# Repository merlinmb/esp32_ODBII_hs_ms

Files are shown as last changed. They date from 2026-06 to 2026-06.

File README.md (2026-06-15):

# Ford Focus 2008 — Dual CAN OBD-II Logger

ESP32-S3 firmware for the **Lilygo T2-CAN** board. Reads both the High-Speed (HS) and Medium-Speed (MS) CAN buses from a Ford Focus 2008 OBD-II connector, hosts a live web dashboard, and publishes data to a Mosquitto MQTT broker.

---

## What It Does

| Feature | Detail |
|---|---|
| HS-CAN (500 kbps) | RPM, speed, coolant temp, IAT, MAF, throttle %, battery voltage, oil temp, DTCs |
| MS-CAN (125 kbps) | Fuel level (Ford broadcast, CAN ID 0x420) |
| Web dashboard | Dark-theme card grid, auto-refreshes every 5 s, served on port 80 |
| MQTT | Publishes full JSON payload every 30 s (configurable) |
| Config | All credentials and pin assignments in `credentials.h` |

---

## Hardware

### Lilygo T2-CAN V1.0

The T2-CAN V1.0 uses a **hybrid CAN architecture** — not two native TWAI controllers as the board name might imply:

| Bus | Controller | Interface | GPIO |
|-----|---|---|---|
| CAN A — HS-CAN (500 kbps) | MCP2515 (external SPI) | SPI | CS=10, SCLK=12, MOSI=11, MISO=13 |
| CAN B — MS-CAN (125 kbps) | ESP32-S3 native TWAI | Direct | TX=7, RX=6 |

The MCP2515 also has a hardware reset (GPIO 9) and interrupt (GPIO 8) line. Pin definitions are in `include/credentials.h` and match the [official LilyGo T2-CAN pin_config.h](https://github.com/Xinyuan-LilyGO/T-2Can/blob/main/libraries/private_library/pin_config.h).

### I2C OLED Display (SH1106 128×64)

Connect via the QWIIC/I2C connector on the board.

**Default pin assignments (adjust in `credentials.h` if different):**

| Signal | GPIO |
|---|---|
| I2C SDA | 17 |
| I2C SCL | 18 |

---

## OBD-II Wiring

The connector used for this build is an [OBD-II 16-pin breakout cable (Amazon UK)](https://www.amazon.co.uk/dp/B0F2HTKXRH?ref=ppx_yo2ov_dt_b_fed_asin_title), which exposes individual colour-coded wires for each pin.

### Wire colour reference (cable pin-out)

| OBD-II Pin | Wire Colour | Standard Function |
|:---:|---|---|
| 1 | Black | Manufacturer-defined |
| 2 | Brown | Manufacturer-defined |
| 3 | Red | MS-CAN High (Ford) |
| 4 | Orange | Chassis Ground |
| 5 | Yellow | Signal Ground |
| 6 | Green | HS-CAN High |
| 7 | Blue | K-Line / ISO 9141 |
| 8 | Purple | Manufacturer-defined |
| 9 | Grey | Manufacturer-defined |
| 10 | White | Manufacturer-defined |
| 11 | Pink | MS-CAN Low (Ford) |
| 12 | Light Green | Manufacturer-defined |
| 13 | Black/White | Manufacturer-defined |
| 14 | Brown/White | HS-CAN Low |
| 15 | Red/White | Manufacturer-defined |
| 16 | Green/White | Battery +12 V |

### T2-CAN connector wiring

#### CAN Bus A — HS-CAN (500 kbps, OBD-II standard)

| T2-CAN Pin | Signal | OBD-II Pin | Wire Colour |
|---|---|:---:|---|
| CANHA | CAN High | 6 | Green |
| CANLA | CAN Low | 14 | Brown/White |
| SGNDA | Signal Ground | 5 | Yellow |
| DGNDA | Digital Ground | 4 | Orange |

#### CAN Bus B — MS-CAN (125 kbps, Ford Medium Speed)

| T2-CAN Pin | Signal | OBD-II Pin | Wire Colour |
|---|---|:---:|---|
| CANHB | CAN High | 3 | Red |
| CANLB | CAN Low | 11 | Pink |
| SGNDB | Signal Ground | 5 | Yellow (shared with Bus A) |
| DGNDB | Digital Ground | 4 | Orange (shared with Bus A) |

#### Power

| T2-CAN Pin | Signal | OBD-II Pin | Wire Colour |
|---|---|:---:|---|
| VIN | +12 V battery | 16 | Green/White |
| GND | Power Ground | 4 | Orange |

> **Note:** OBD-II pins 3 and 11 are Ford-proprietary MS-CAN. They are not present on non-Ford vehicles.

> **Termination:** The vehicle's CAN buses are already terminated at the ECU end. Do **not** add external 120 Ω resistors — the T2-CAN transceivers have on-board termination jumpers; leave them **open** (or cut the trace) when connecting to an in-vehicle bus.

---

## Ford Focus 2008 CAN Bus Notes

### HS-CAN (500 kbps)
Carries powertrain data. Accessed via standard OBD-II Mode 01 PIDs using functional address `0x7DF`. ECU responds on `0x7E8`.

### MS-CAN (125 kbps)
Carries body/comfort data (fuel gauge, HVAC, instrument cluster). Ford ECUs broadcast data continuously — no request frames needed. The firmware listens passively.

**Known MS-CAN broadcast IDs:**

| CAN ID | Content | Byte | Formula |
|---|---|---|---|
| 0x420 | Fuel level | 0 | `byte / 2.55` → % |

Additional IDs can be added in `src/can_ms.cpp` as you discover them with a CAN sniffer.

---

## Ford Focus MK2 (2007–2008, UK) — Model-Specific Notes

This section documents the specific CAN bus architecture of the **Ford Focus MK2 C170 platform** (2005–2008, UK market) and confirms compatibility with this firmware.

### Dual CAN Bus Architecture

The Focus MK2 is one of Ford's earliest models to use a dual-bus CAN architecture. This is why a standard ELM327 dongle cannot access body modules without a hardware HS/MS-CAN toggle switch (as sold by ELMConfig/FORScan adapters) — a standard OBD-II dongle only sees pins 6 and 14 (HS-CAN).

| Bus | OBD-II Pins | Speed | Purpose |
|-----|---|---|---|
| HS-CAN | Pin 6 (High), Pin 14 (Low) | 500 kbps | Powertrain, ABS, transmission |
| MS-CAN | Pin 3 (High), Pin 11 (Low) | 125 kbps | Body, comfort, instrument cluster |

> Pins 3 and 11 are **Ford-proprietary** — they carry no signal on non-Ford vehicles.

### Which Modules Live on Each Bus

**HS-CAN (500 kbps) — accessed by this firmware via MCP2515:**

| Module | Abbrev | What it provides |
|---|---|---|
| Powertrain Control Module | PCM | RPM, speed, temps, MAF, throttle, DTCs |
| Transmission Control Module | TCM | Gear, torque |
| Anti-lock Braking System | ABS/HEC | Wheel speeds |
| Electric Power Assisted Steering | EHPAS | Steering load |
| Body Control Module | BCM | Some body signals |

**MS-CAN (125 kbps) — listened to passively by this firmware via TWAI:**

| Module | Abbrev | What it provides |
|---|---|---|
| Generic Electronic Module | GEM | Lighting, wipers, central locking |
| Driver/Passenger Door Modules | DDM / PDM | Window, mirror control |
| Electronic Automatic Temp Control | EATC | Climate |
| Restraints Control Module | RCM | Airbag |
| Instrument Cluster | IC | Fuel gauge, odometer, warnings |
| Keyless Vehicle Module | KVM | Remote locking |
| Parking Aid Module | PAM | Sensors |

### OBD-II Diagnostic Protocol (HS-CAN)

The Focus MK2 UK uses **ISO 15765-4** (CAN 11-bit, 500 kbps) for OBD-II diagnostics. All standard Mode 01 PIDs are supported:

| PID | Parameter | Formula |
|-----|---|---|
| 0x0C | Engine RPM | `((A×256)+B) / 4` |
| 0x0D | Vehicle speed | `A` km/h |
| 0x05 | Coolant temperature | `A − 40` °C |
| 0x0F | Intake air temperature | `A − 40` °C |
| 0x10 | MAF air flow | `((A×256)+B) / 100` g/s |
| 0x11 | Throttle position | `A × 100 / 255` % |
| 0x42 | Battery voltage | `((A×256)+B) / 1000` V |
| 0x5C | Oil temperature | `A − 40` °C |
| 0x01 | DTC status / MIL | Bit 7 of A = MIL on/off; bits 0–6 = DTC count |

Request address: `0x7DF` (functional broadcast to all ECUs)
Response address: `0x7E8` (PCM — engine ECU)

### MS-CAN Fuel Level (Unverified — Needs In-Car Confirmation)

The instrument cluster on the MS-CAN bus broadcasts fuel level as a periodic frame. CAN ID `0x420`, byte 0, scaled as `byte / 2.55` → % is **widely cited in Ford reverse-engineering communities** for this platform, but has not been independently verified against a production UK MK2.

**To verify or find the correct ID on your car:**

1. Enable serial logging and watch MS-CAN output — the firmware logs all unrecognised frame IDs at debug level
2. With a nearly-full tank, note which IDs are present
3. Remove ~5 litres, re-check — the ID whose byte 0 value changed is the fuel level frame
4. Update `MS_ID_FUEL_LEVEL` in `src/can_ms.cpp` if the ID differs

### Termination

Do **not** add 120 Ω termination resistors. The vehicle bus is already terminated at both ends (ECU and instrument cluster). The T2-CAN board has optional termination jumpers — leave them **open** when connected to an in-vehicle bus, otherwise you'll create a 60 Ω net impedance and cause bus errors.

### Known Limitations on This Platform

- **Oil temperature (PID 0x5C):** May not be supported on all MK2 engine variants. The 1.6 Duratec petrol does not have an oil temp sensor — PID queries will time out silently.
- **Battery voltage (PID 0x42):** Returns ECU supply voltage, not alternator voltage directly. Values are typically 13.8–14.4 V at idle with engine running.
- **MAF (PID 0x10):** Not present on diesel variants (use MAP instead). Queries will time out on TDCi engines.
- **MS-CAN availability:** The MS-CAN bus is only active with ignition on (position II). It goes silent within seconds of key-off, which will trigger the MS-CAN silence timeout in the firmware.

---

## Software Setup

### Prerequisites

- [PlatformIO](https://platformio.org/) (VS Code extension or CLI)
- USB cable to COM3

### 1. Clone / open the project

Open the `esp32_ODBII_hs_ms` folder in VS Code with the PlatformIO extension installed.

### 2. Create credentials

```bash
cp credentials.h.example credentials.h
```

Edit `credentials.h` and fill in your values:

```cpp
#define WIFI_SSID              "MyNetwork"
#define WIFI_PASSWORD          "MyPassword"
#define MQTT_BROKER            "192.168.1.100"
#define MQTT_PORT              1883
#define MQTT_TOPIC             "car/focus/obd"
#define MQTT_PUBLISH_INTERVAL_MS  30000   // 30 s

// T2-CAN V1.0 — MCP2515 SPI pins for HS-CAN
#define MCP2515_CS_PIN         10
#define MCP2515_RST_PIN        9
#define MCP2515_INT_PIN        8
#define SPI_SCLK_PIN           12
#define SPI_MOSI_PIN           11
#define SPI_MISO_PIN           13

// T2-CAN V1.0 — native TWAI pins for MS-CAN
#define CAN_MS_TX_PIN          7
#define CAN_MS_RX_PIN          6
```

### 3. Build and flash

```bash
pio run --target upload
```

Or use the PlatformIO toolbar in VS Code (→ Upload).

### 4. Monitor serial output

```bash
pio device monitor
```

The device prints WiFi connection status, CAN bus state, and each MQTT publish to the serial console at 115200 baud.

---

## Web Dashboard

Once connected to WiFi, open a browser to the device's IP address (printed on serial):

```
http://192.168.x.x/
```

The dashboard auto-refreshes every 5 seconds. Values turn amber when stale (> 10 s since last CAN update) and red when the bus is disconnected.

The raw JSON data is also available at:

```
http://192.168.x.x/data
```

---

## MQTT Payload

Published as a flat JSON object to the configured topic:

```json
{
  "rpm": 820.0,
  "speed_kmh": 0.0,
  "coolant_temp_c": 87.5,
  "intake_air_temp_c": 22.0,
  "maf_g_per_s": 3.1,
  "throttle_pct": 0.0,
  "battery_voltage": 14.1,
  "oil_temp_c": 91.0,
  "dtc_present": false,
  "dtc_count": 0,
  "fuel_level_pct": 62.4,
  "hs_connected": true,
  "ms_connected": true
}
```

---

## Project Structure

```
credentials.h          — your local config (gitignored)
credentials.h.example  — template committed to repo
platformio.ini         — build config, COM3, board
src/
  main.cpp             — setup, loop, FreeRTOS task launch
  obd_data.h           — shared VehicleData struct + mutex
  can_hs.h / .cpp      — HS-CAN FreeRTOS task (OBD-II request/response)
  can_ms.h / .cpp      — MS-CAN FreeRTOS task (Ford broadcast listener)
  web_server.h / .cpp  — async HTTP server, HTML in PROGMEM
  mqtt_client.h / .cpp — MQTT publish wrapper
docs/
  superpowers/specs/   — design documentation
```

---

## Troubleshooting

| Symptom | Likely cause |
|---|---|
| CAN bus install fails | Wrong GPIO pins — check `credentials.h` against your board schematic |
| HS-CAN shows no data | Bus speed mismatch or missing termination — verify 500 kbps |
| MS-CAN fuel stays 0 | CAN ID 0x420 not present on your trim — sniff the bus to find the correct ID |
| WiFi not connecting | Check SSID/password in `credentials.h`; device must be on 2.4 GHz |
| MQTT not publishing | Check broker IP, port 1883 open, no auth required (or add auth to `mqtt_client.cpp`) |
| Web page not loading | Find IP in serial monitor; ensure device and browser on same subnet |

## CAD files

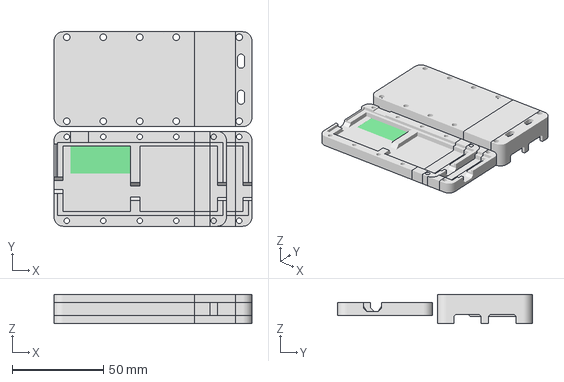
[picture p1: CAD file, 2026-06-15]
3dmodels/Lilygo_T_2Can_Enclosure_extended components.3mf
108.5 x 106.6 x 16.0 mm

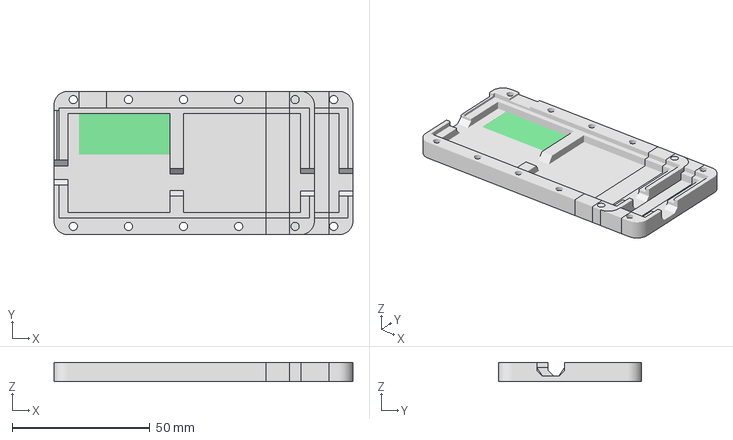
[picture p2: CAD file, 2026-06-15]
3dmodels/Lilygo_T_2Can_Enclosure_base_v2.3mf
108.5 x 52.0 x 7.00 mm

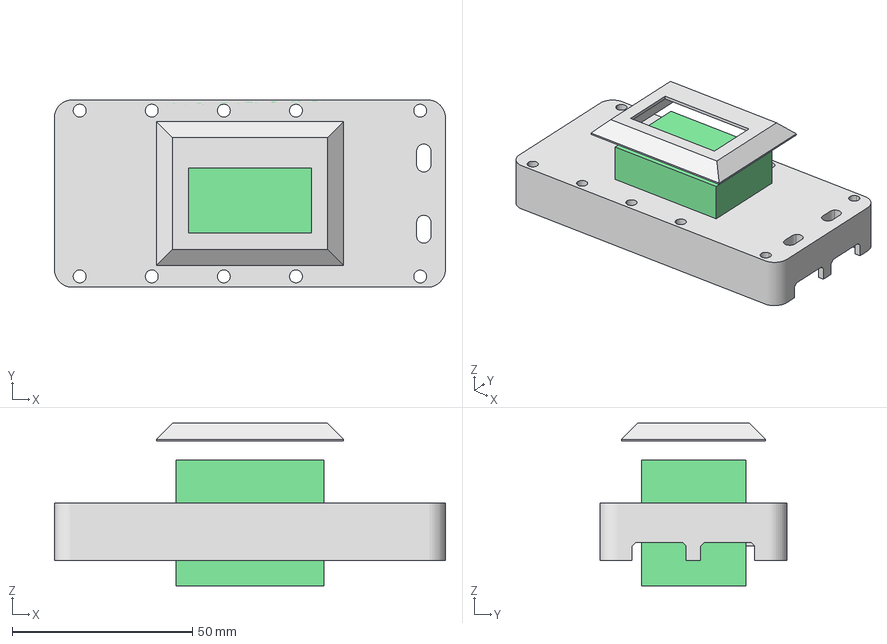
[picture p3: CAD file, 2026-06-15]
3dmodels/Lilygo_T_2Can_Enclosure_Top_v2.3mf
108.5 x 52.0 x 45.1 mm

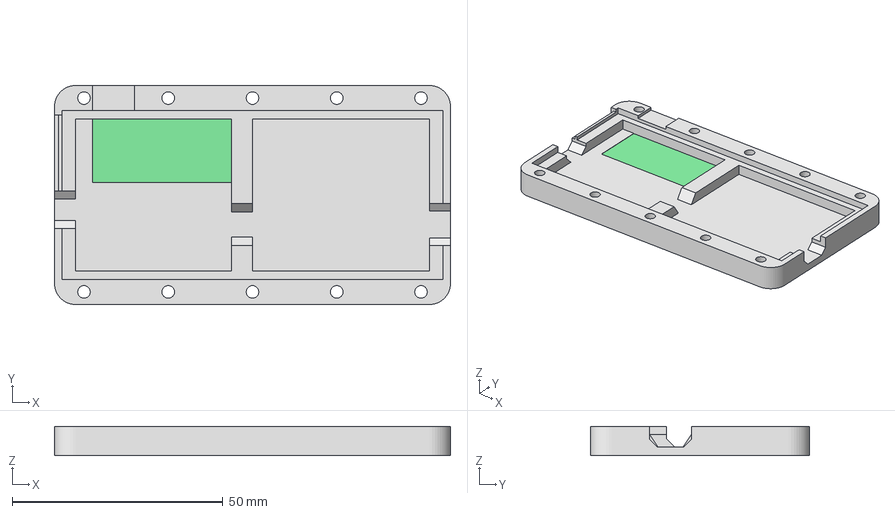
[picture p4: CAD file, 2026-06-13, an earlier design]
3dmodels/Lilygo_T_2Can_Enclosure_base.3mf
94.0 x 52.0 x 7.00 mm

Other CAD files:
3dmodels/Lilygo_T_2Can_Enclosure_Top_v2.stl
3dmodels/Lilygo_T_2Can_Enclosure_base.stl
3dmodels/Lilygo_T_2Can_Enclosure_base_v2.stl

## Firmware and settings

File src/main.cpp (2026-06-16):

#include <Arduino.h>
#include <SPI.h>
#include <WiFi.h>
#include "credentials.h"
#include "obd_data.h"
#include "can_hs.h"
#include "can_ms.h"
#include "web_server.h"
#include "mqtt_client.h"
#include "sleep_manager.h"
#include "display.h"
#include "esp_sleep.h"

// Globals defined here, declared extern in obd_data.h
VehicleData g_vehicle = {
    .rpm               = NAN,
    .speed_kmh         = NAN,
    .coolant_temp_c    = NAN,
    .intake_air_temp_c = NAN,
    .maf_g_per_s       = NAN,
    .throttle_pct      = NAN,
    .battery_voltage   = NAN,
    .oil_temp_c        = NAN,
    .fuel_level_pct    = NAN,
};
SemaphoreHandle_t g_data_mutex = nullptr;

static WiFiClient s_mqtt_wifi_client;

static void wifi_connect() {
    Serial.printf("[WiFi] connecting to %s ...\n", WIFI_SSID);
    WiFi.mode(WIFI_STA);
    WiFi.begin(WIFI_SSID, WIFI_PASSWORD);
    uint8_t attempts = 0;
    while (WiFi.status() != WL_CONNECTED && attempts < 30) {
        delay(500);
        Serial.print('.');
        attempts++;
    }
    Serial.println();
    if (WiFi.status() == WL_CONNECTED) {
        Serial.printf("[WiFi] connected, IP: %s\n", WiFi.localIP().toString().c_str());
    } else {
        Serial.println("[WiFi] failed to connect — continuing without network");
    }
}

void setup() {
    Serial.begin(115200);
    delay(500);

    esp_sleep_wakeup_cause_t wakeup = esp_sleep_get_wakeup_cause();
    if (wakeup == ESP_SLEEP_WAKEUP_EXT1) {
        Serial.println("\n[Boot] wakeup from deep sleep (CAN activity on GPIO8)");
    } else if (wakeup != ESP_SLEEP_WAKEUP_UNDEFINED) {
        Serial.printf("\n[Boot] wakeup cause: %d\n", (int)wakeup);
    }

    Serial.println("\n[Boot] Ford Focus OBD-II logger starting");

    g_data_mutex = xSemaphoreCreateMutex();
    diag_log_init();

    sleep_manager_init();

    SPI.begin(SPI_SCLK_PIN, SPI_MISO_PIN, SPI_MOSI_PIN, MCP2515_CS_PIN);

    wifi_connect();
    web_server_begin();
    mqtt_setup(s_mqtt_wifi_client);
    display_init();

    // HS-CAN stays on Core 1 because MCP2515 SPI transfers can block.
    xTaskCreatePinnedToCore(
        can_hs_task, "can_hs", 6144, nullptr, 4, nullptr, 1
    );
    // MS-CAN uses timed TWAI receives, so it can live on Core 0 and free Core 1
    // for the Arduino loop and async web server work.
    xTaskCreatePinnedToCore(
        can_ms_task, "can_ms", 6144, nullptr, 4, nullptr, 0
    );
    // MQTT on Core 0 — TCP connect blocks; keep it off Core 1 and out of loop().
    xTaskCreatePinnedToCore(
        mqtt_task, "mqtt", 4096, nullptr, 2, nullptr, 0
    );

    Serial.println("[Boot] tasks started — open http://" + WiFi.localIP().toString());
}

void loop() {
    display_loop();
    sleep_manager_check();

    if (WiFi.status() != WL_CONNECTED) {
        Serial.println("[WiFi] reconnecting...");
        WiFi.reconnect();
        delay(500);
        return;
    }

    delay(10);
}

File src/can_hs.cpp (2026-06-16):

#include "can_hs.h"
#include "obd_data.h"
#include "credentials.h"
#include <Arduino.h>
#include <SPI.h>
#include <mcp2515.h>
#include <esp_task_wdt.h>

// OBD-II Mode 01 PID definitions
#define PID_ENGINE_LOAD     0x04
#define PID_COOLANT_TEMP    0x05
#define PID_RPM             0x0C
#define PID_SPEED           0x0D
#define PID_INTAKE_AIR_TEMP 0x0F
#define PID_MAF             0x10
#define PID_THROTTLE        0x11
#define PID_BATTERY_VOLTAGE 0x42
#define PID_OIL_TEMP        0x5C
#define PID_DTC_STATUS      0x01

#define OBD_REQUEST_ID          0x7DF
#define OBD_RESPONSE_ID         0x7E8
#define OBD_RESPONSE_TIMEOUT_MS 25

#define HS_FAIL_THRESHOLD 8

// Pointer instead of global instance — avoids the MCP2515 constructor calling
// SPI.begin() during C++ static init (before setup()), which corrupts the GPIO
// matrix and interferes with Wire/I2C on GPIO1/GPIO2 (OLED).
static MCP2515* s_mcp = nullptr;

static bool install_hs_can() {
    // Create the MCP2515 instance the first time, passing &SPI so the
    // constructor does not call SPI.begin() again.
    if (s_mcp == nullptr) {
        s_mcp = new MCP2515(MCP2515_CS_PIN, 10000000UL, &SPI);
    }

    pinMode(MCP2515_RST_PIN, OUTPUT);
    digitalWrite(MCP2515_RST_PIN, LOW);
    vTaskDelay(pdMS_TO_TICKS(10));
    digitalWrite(MCP2515_RST_PIN, HIGH);
    vTaskDelay(pdMS_TO_TICKS(10));

    s_mcp->reset();
    vTaskDelay(pdMS_TO_TICKS(10));

    if (s_mcp->setBitrate(CAN_500KBPS) != MCP2515::ERROR_OK) {
        diag_log("[HS-CAN] setBitrate failed");
        return false;
    }
    if (s_mcp->setNormalMode() != MCP2515::ERROR_OK) {
        diag_log("[HS-CAN] setNormalMode failed");
        return false;
    }
    diag_log("[HS-CAN] MCP2515 started OK (500 kbps)");
    return true;
}

static bool send_pid_request(uint8_t pid) {
    struct can_frame req = {};
    req.can_id  = OBD_REQUEST_ID;
    req.can_dlc = 8;
    req.data[0] = 0x02;
    req.data[1] = 0x01;
    req.data[2] = pid;
    return s_mcp->sendMessage(&req) == MCP2515::ERROR_OK;
}

static bool recv_pid_response(uint8_t pid, uint8_t* out_a, uint8_t* out_b) {
    struct can_frame resp;
    unsigned long deadline = millis() + OBD_RESPONSE_TIMEOUT_MS;
    while (millis() < deadline) {
        if (s_mcp->readMessage(&resp) == MCP2515::ERROR_OK) {
            if (resp.can_id == OBD_RESPONSE_ID &&
                resp.can_dlc >= 4 &&
                resp.data[1] == 0x41 &&
                resp.data[2] == pid) {
                *out_a = resp.data[3];
                *out_b = (resp.can_dlc >= 5) ? resp.data[4] : 0;
                return true;
            }
        }
        vTaskDelay(1);
    }
    return false;
}

static bool query_pid(uint8_t pid, uint8_t* a, uint8_t* b) {
    if (!send_pid_request(pid)) return false;
    return recv_pid_response(pid, a, b);
}

static void poll_dtc_status() {
    uint8_t a, b;
    if (!query_pid(PID_DTC_STATUS, &a, &b)) return;
    bool mil    = (a & 0x80) != 0;
    uint8_t cnt = (a & 0x7F);
    if (xSemaphoreTake(g_data_mutex, pdMS_TO_TICKS(10)) == pdTRUE) {
        g_vehicle.dtc_present = mil;
        g_vehicle.dtc_count   = cnt;
        xSemaphoreGive(g_data_mutex);
    }
    if (mil) diag_log("[HS-CAN] MIL on — %u DTC(s) present", cnt);
}

void can_hs_task(void* /*pvParameters*/) {
    diag_log("[HS-CAN] task started, connecting via MCP2515...");

    // Do NOT subscribe to task WDT — MCP2515 SPI transfers block with no timeout
    // and will always trigger it when the bus is absent or slow to respond.
    esp_task_wdt_delete(NULL);

    while (!install_hs_can()) {
        diag_log("[HS-CAN] retrying in 3 s...");
        vTaskDelay(pdMS_TO_TICKS(3000));
    }

    if (xSemaphoreTake(g_data_mutex, pdMS_TO_TICKS(10)) == pdTRUE) {
        g_vehicle.hs_connected = true;
        g_vehicle.reconnect_hs = false;
        xSemaphoreGive(g_data_mutex);
    }

    uint8_t a, b;
    uint32_t dtc_cycle   = 0;
    uint8_t  fail_streak = 0;

    for (;;) {
        bool want_reconnect = false;
        if (xSemaphoreTake(g_data_mutex, pdMS_TO_TICKS(10)) == pdTRUE) {
            want_reconnect = g_vehicle.reconnect_hs;
            xSemaphoreGive(g_data_mutex);
        }
        if (want_reconnect) {
            diag_log("[HS-CAN] reconnect requested — resetting MCP2515...");
            if (xSemaphoreTake(g_data_mutex, pdMS_TO_TICKS(10)) == pdTRUE) {
                g_vehicle.hs_connected = false;
                g_vehicle.reconnect_hs = false;
                xSemaphoreGive(g_data_mutex);
            }
            vTaskDelay(pdMS_TO_TICKS(500));
            while (!install_hs_can()) {
                diag_log("[HS-CAN] reconnect failed, retrying in 3 s...");
                vTaskDelay(pdMS_TO_TICKS(3000));
            }
            if (xSemaphoreTake(g_data_mutex, pdMS_TO_TICKS(10)) == pdTRUE) {
                g_vehicle.hs_connected = true;
                xSemaphoreGive(g_data_mutex);
            }
            fail_streak = 0;
            diag_log("[HS-CAN] reconnect succeeded");
        }

        // --- RPM ---
        if (query_pid(PID_RPM, &a, &b)) {
            float v = ((uint16_t)a * 256 + b) / 4.0f;
            if (xSemaphoreTake(g_data_mutex, pdMS_TO_TICKS(10)) == pdTRUE) {
                g_vehicle.rpm = v;
                g_vehicle.last_hs_update_ms = millis();
                xSemaphoreGive(g_data_mutex);
            }
            if (fail_streak >= HS_FAIL_THRESHOLD) {
                diag_log("[HS-CAN] connection recovered (RPM responding)");
                if (xSemaphoreTake(g_data_mutex, pdMS_TO_TICKS(10)) == pdTRUE) {
                    g_vehicle.hs_connected = true;
                    xSemaphoreGive(g_data_mutex);
                }
            }
            fail_streak = 0;
        } else {
            fail_streak++;
            if (fail_streak == HS_FAIL_THRESHOLD) {
                diag_log("[HS-CAN] no response from ECU — %u consecutive timeouts", fail_streak);
                if (xSemaphoreTake(g_data_mutex, pdMS_TO_TICKS(10)) == pdTRUE) {
                    g_vehicle.hs_connected = false;
                    xSemaphoreGive(g_data_mutex);
                }
            }
        }
        vTaskDelay(pdMS_TO_TICKS(100));

        // --- Speed ---
        if (query_pid(PID_SPEED, &a, &b)) {
            if (xSemaphoreTake(g_data_mutex, pdMS_TO_TICKS(10)) == pdTRUE) {
                g_vehicle.speed_kmh = a;
                xSemaphoreGive(g_data_mutex);
            }
        }
        vTaskDelay(pdMS_TO_TICKS(100));

        // --- Coolant temp ---
        if (query_pid(PID_COOLANT_TEMP, &a, &b)) {
            if (xSemaphoreTake(g_data_mutex, pdMS_TO_TICKS(10)) == pdTRUE) {
                g_vehicle.coolant_temp_c = (float)a - 40.0f;
                xSemaphoreGive(g_data_mutex);
            }
        }
        vTaskDelay(pdMS_TO_TICKS(100));
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

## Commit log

2026-06-13 Refactor code structure for improved readability and maintainability
    [Lilygo_T_2Can_Enclosure_base.3mf, Lilygo_T_2Can_Enclosure_base.stl]
2026-06-16 Refactor CAN and MQTT handling for improved stability and performance; update sleep manager for better wake handling
    [can_hs.cpp, display.cpp, main.cpp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]
2026-10-31 Refactor display handling to use Adafruit SH110X; update OLED pin definitions and improve deep sleep wake configuration
